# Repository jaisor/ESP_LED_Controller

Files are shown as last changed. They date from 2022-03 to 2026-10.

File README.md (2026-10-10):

# RingLight ESP LED Controller

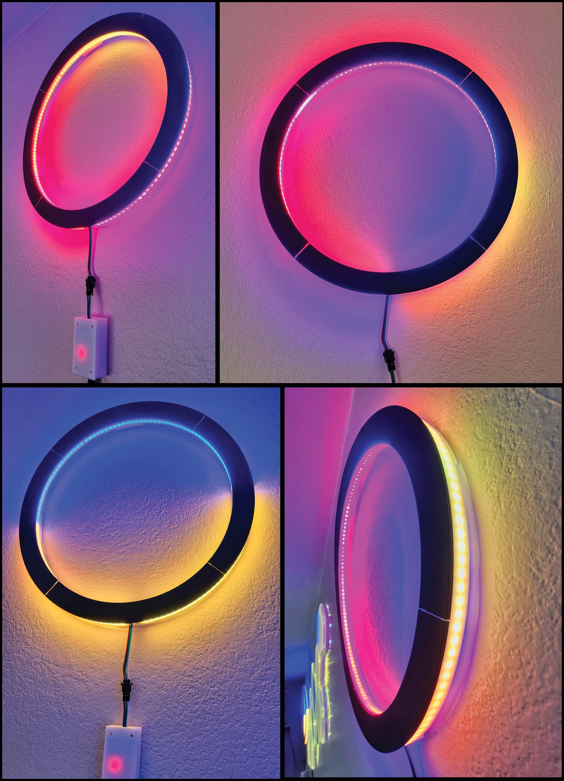
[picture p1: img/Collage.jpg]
Glamor shot


## Features
* Two LED rings - outer (141 LEDs) and inner (126 LEDs) wired up in series for a total of 267 LEDs
* Controlled by ESP32 (most stable). Code is compatible with ESP8266, but I was suffering stability issues with wifi and longer LED strips.
* WiFi connected and managed
    * creates a default AP, listening to http://192.168.4.1
    * capable of joining existing 2.4GHz networks
    * serves a webpage for managing LED - mode, brightness, cycling and power-save hours
    * LED setup page (`/led`) - layout (single strip, dual strip, ring light), LED count, data pin(s), chipset and color order
    * configuration export and import as a JSON file on the Device page
    * Mode Configurator (`/modes`) - define up to 8 custom modes: name, color palette (up to 8 colors, smooth or hard transitions), effect, direction, speed and palette repeats. Effects depend on the layout: color fade, edge to edge, twinkle, falling stars, flickering flame (from either end, both ends or the center - on a ring light in one or both rings), breathing, theater chase, scanner, color wipe and lightning everywhere, center to edge on strips, circling, ring halves and ring to ring on a ring light. A mode's **Code** button shows it as a short JSON code that can be pasted into another controller's configurator
* MQTT and Home Assistant (Device page) - set the broker and the controller shows up in Home Assistant through MQTT discovery as a light: on/off, brightness, and the modes of the current layout (custom modes included) as effects, plus WiFi signal and IP diagnostics. Other MQTT clients can use the same topics, see below
* Firmware update over WiFi - new `firmware.bin` file can be uploaded at `/update` after the IP address

## Components
* ESP32 - https://www.amazon.com/gp/product/B086MGH7JV
* JST SM 3PIN LED Connector - https://www.amazon.com/gp/product/B075K4HLTQ
* DC power connector - https://www.amazon.com/gp/product/B01N8VV78D
* WS2812B LED strip high density strips 144 LEDs per strip x 2 - https://www.amazon.com/gp/product/B088FKZWDQ
* DC 5v adapter - https://www.amazon.com/gp/product/B078RXZM4C

## 3D filament 
I used the ones below but likely many others will work. Make sure the white is translucent enough, print a 3 layer sheet and put it in-front of some LEDs.
* ESUN PLA+ warm white - https://www.amazon.com/gp/product/B01EKEMIIS
* ERYONE Matte PLA black - https://www.amazon.com/gp/product/B08HX1XF55

## Assembly and wiring

Print 4 of each:
* [Dark Ring](stl/DarkRing.stl)
* [Light Ring](stl/LightRing.stl)
* [Bridge Hanger](stl/Hanger.stl)

Assemble as described below. Rotate the light ring segments by 45 degrees so they join in the middle of the dark ring segments. 
This improves stability. If loose-fitting, use a few drops of superglue to set the dark and light rings together.
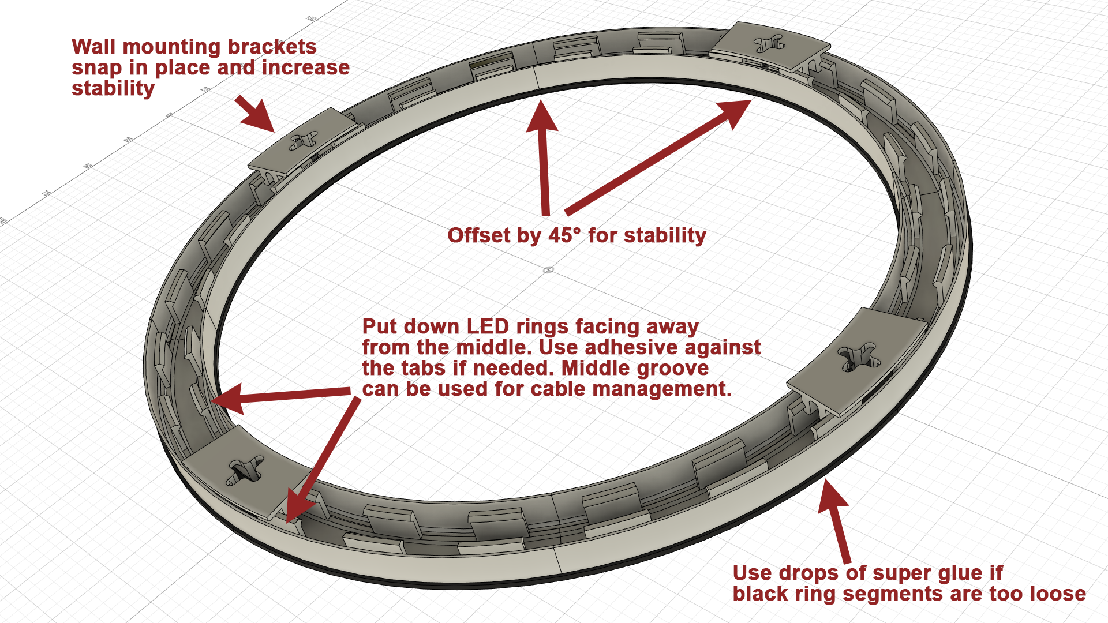
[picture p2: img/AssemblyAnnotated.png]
Assembly diagram


Cut the two LED strips to 141 and 126 LEDs. Keep as many of the existing wires and connectors as possible. 
Wire the strips data in series - outer first then inner. The beginning of the outer ring data pin goes to the connector data pin. 
Join the power wires in parallel: 5V/VCC together to the 5V connector pin; GND(-) together to GND on connector pin. 
Providing power to both start and ends of the strips reduces voltage sag and ensures even light at all brightness levels.

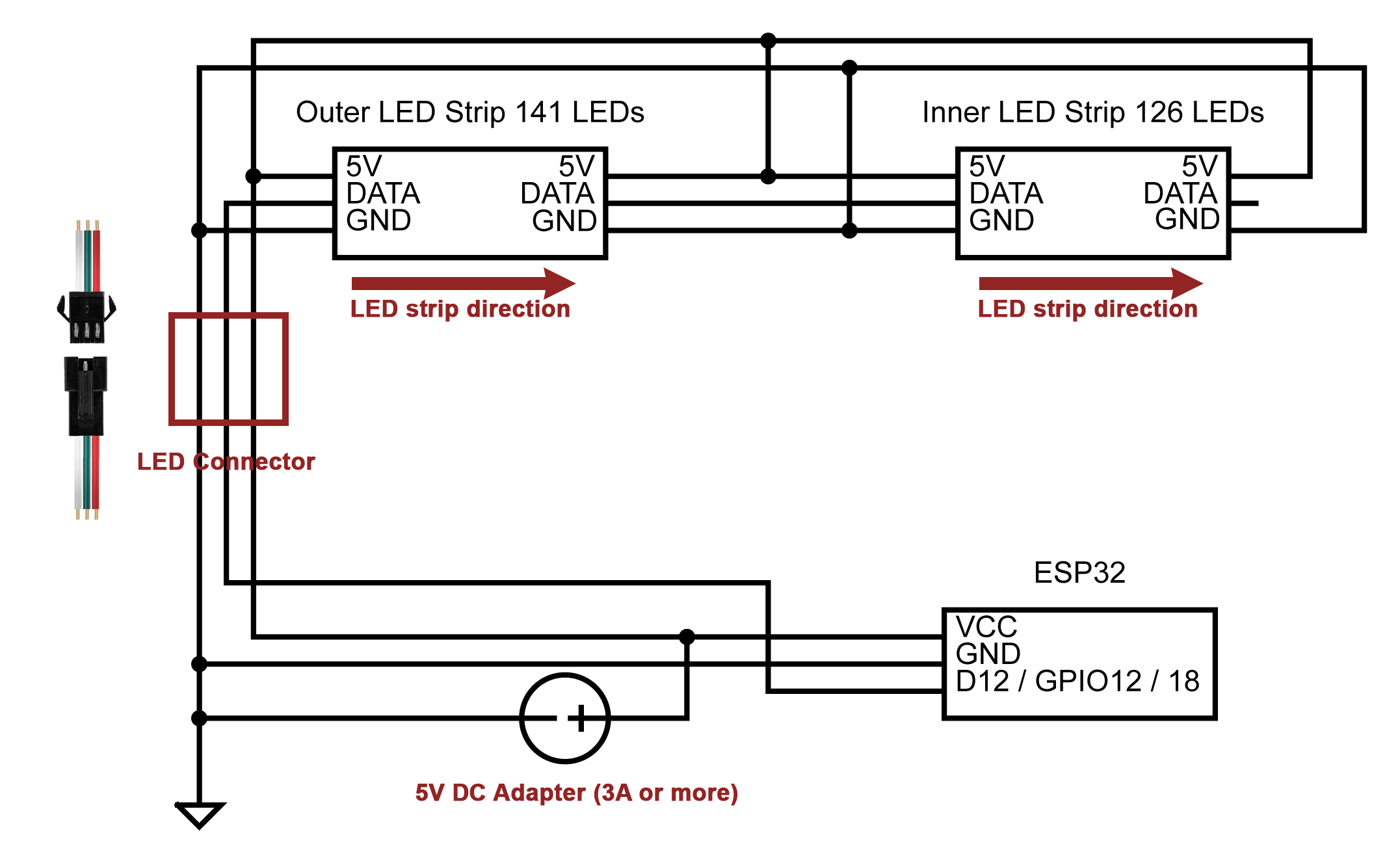
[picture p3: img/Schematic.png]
Schematic

Wiring Closeup
Wiring Complete

By default the LEDs data is connected to pin 12 on the ESP, but most other GPIO pins can be used if needed - pick the pin on the LED setup page.

__LED data pin = 12__ - GPIO12 - above VIN (5V), GND and GPIO13

After first boot, open `http://<device_ip>/led` (or ⚙️ → LED Setup) and set:
* Layout: __Ring light__
* Total LEDs: __267__, outer ring LEDs: __141__
* Chipset __WS2812B__, color order __GRB__

The ring modes (Slava Ukraini, Dual Ring, Ring ... Colors, Honey Amber, Ring Pride) only show up with the ring light layout.

ESP32 pins


Solder the power and data cables between the LED connector, ESP32 and DC connector as shown below, using the basic 3D printable enclosure.
The board is mounted above the DC connector with 3mm screws

ESP32 box assembled
ESP32 box

Enclosure STL files. Print in PLA, PETG or any other hard filament.
* [ESP32 Case STL](stl/ESP32Case.stl)
* [ESP32 Lid STL](stl/ESP32Lid.stl)

## Configuration.h

This file configures compile-time features and the defaults used after a factory reset, like:
* default LED data pin(s) and the list of GPIOs offered on the LED setup page
* WiFi AP name/password
* default LED layout, strip size, color order and brightness

Everything LED-hardware related can be changed at runtime on the LED setup page.
## MQTT

Enable it on the Device page by setting the MQTT server (and username/password if the broker requires one - the Home Assistant Mosquitto add-on does). Topics live under `<base topic>/<device id>`, both shown on the Device page:

| Topic | Direction | Payload |
| --- | --- | --- |
| `.../availability` | device → | `online` / `offline`, retained |
| `.../state` | device → | `{"state": "ON", "brightness": 0-255, "color_mode": "brightness", "effect": "<mode name>"}`, retained |
| `.../set` | → device | any of `{"state": "ON"/"OFF", "brightness": 0-255, "effect": "<mode name>"}` |
| `.../config` | → device | configuration JSON, same fields as the Device page backup file; saved, and the device reboots for WiFi, MQTT or LED hardware changes |
| `.../json` | device → | telemetry (IP, RSSI, uptime, mode, ...), every 5 minutes, retained |

With Home Assistant discovery enabled the device publishes its entities to `homeassistant/light/<device id>/config` and `homeassistant/sensor/<device id>_*/config`, and re-publishes them when Home Assistant restarts or the mode list changes.

## Migrating to the larger app partitions

Firmware for the `esp32`, `esp32c3` and `esp32s3` environments is built for `min_spiffs.csv` (two 1.9MB app slots); it no longer fits the 1.25MB slots of the framework's `default.csv` that older builds used. A normal OTA update can't fix that - it never rewrites the partition table - so `/update` on an older device rejects the new `firmware.bin` (safely, nothing changes). Flash over USB where you can; for devices that are hard to reach there is a one-off migrator firmware:

1. Build it for the board: `pio run -e esp32_migrator` (or `esp32c3_migrator`, `esp32s3_migrator`). The Xiao ESP32-S3 doesn't need it - its 8MB layout didn't change.
2. Upload `.pio/build/<env>_migrator/firmware.bin` through the device's existing `/update` page.
3. The migrator joins the saved WiFi network (or opens an access point `<name>_<chip id>_migrator`, password `password123`, at http://192.168.4.1) and shows the current partition table. Settings are only read, never changed.
4. Click **Migrate partition table**. It writes `min_spiffs.csv` to the partition table, verifies it and reboots into itself.
5. Upload the normal `firmware.bin` on the migrator's page. The controller comes back with its settings.

The migrator only writes the table when it recognizes `default.csv`, refuses on flash encryption or secure boot, and puts the old table back if the write doesn't verify. The write itself takes a fraction of a second, but a power cut during it leaves a board that needs USB - so try it on a board within USB reach first.

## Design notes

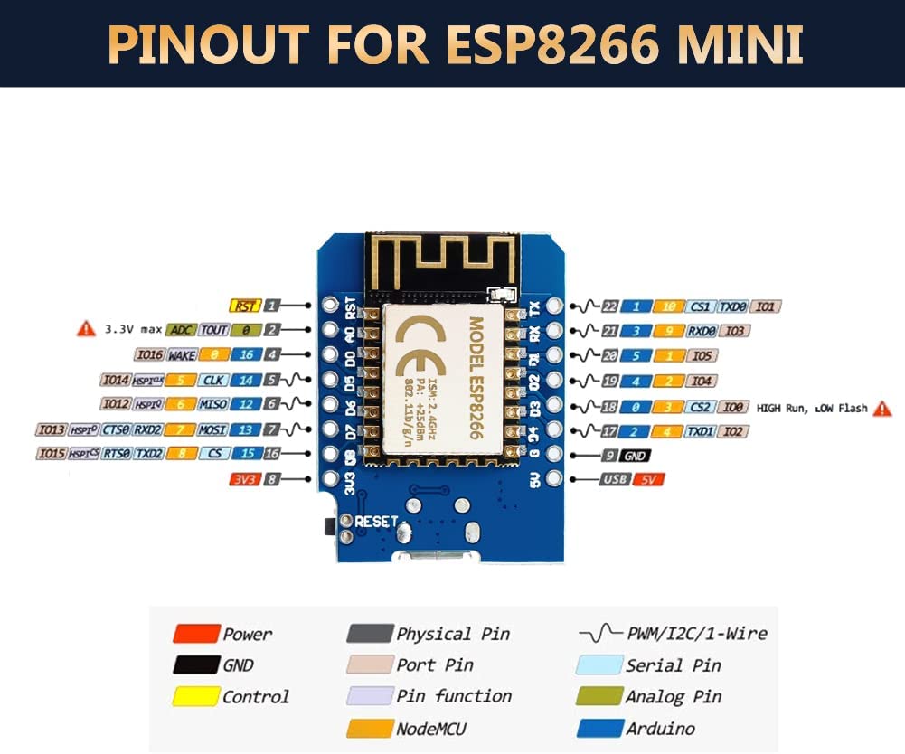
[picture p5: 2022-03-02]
img/ESP8266_pins.jpg

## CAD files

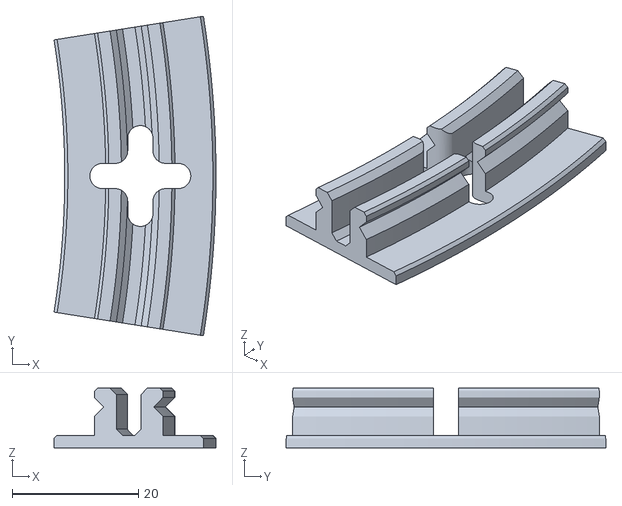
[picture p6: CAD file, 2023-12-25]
stl/Hanger.stl
25.7 x 50.7 x 9.50

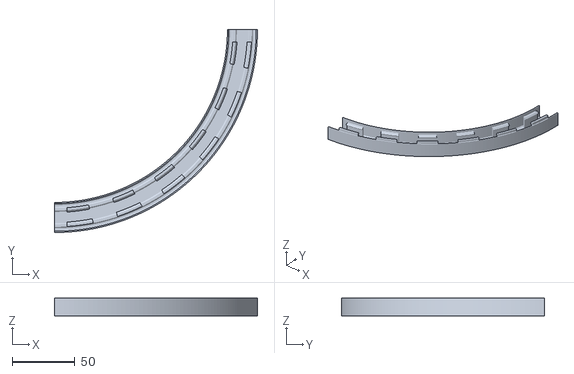
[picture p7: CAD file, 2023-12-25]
stl/LightRing.stl
162.0 x 162.0 x 14.0

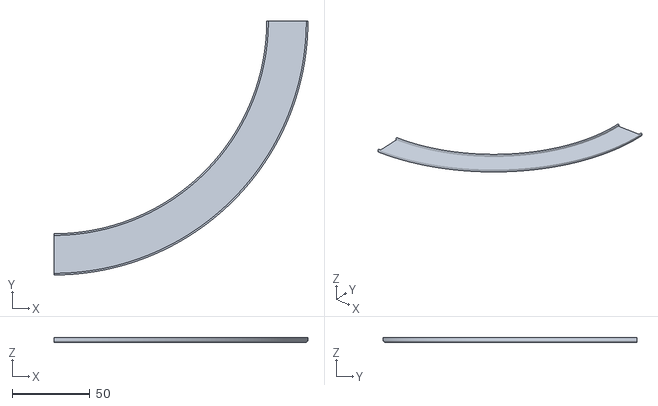
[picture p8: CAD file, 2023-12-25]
stl/DarkRing.stl
163.3 x 163.3 x 3.00

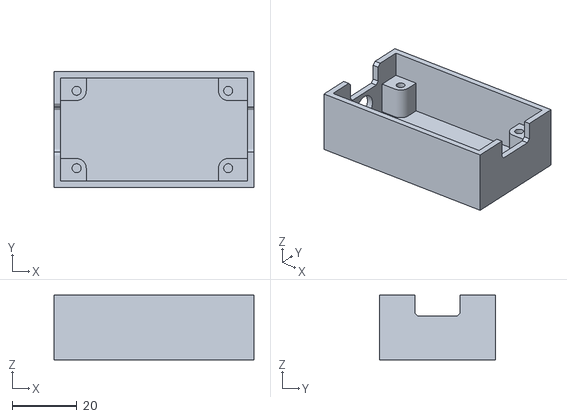
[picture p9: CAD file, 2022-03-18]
stl/ESP32Case.stl
62.0 x 36.0 x 20.0

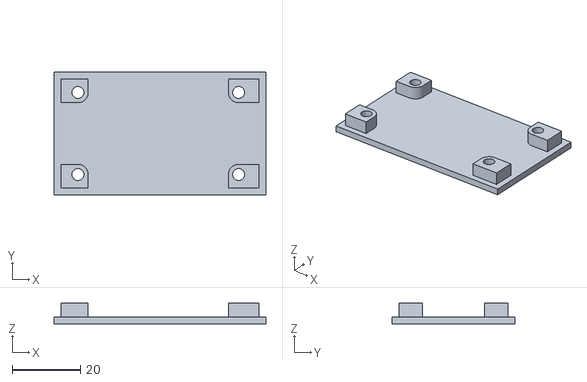
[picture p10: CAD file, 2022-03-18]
stl/ESP32Lid.stl
62.0 x 36.0 x 6.00

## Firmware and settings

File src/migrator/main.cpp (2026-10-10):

// Partition migrator - a one-off firmware, built by the *_migrator environments.
//
// Moves an ESP32 / ESP32-C3 / ESP32-S3 with 4MB flash from the framework's default.csv (two 1.25MB
// app slots) to min_spiffs.csv (two 1.9MB slots) over the air, since a normal OTA update never
// rewrites the partition table and the current firmware no longer fits a 1.25MB slot.
//
//   1. Upload this firmware with the old firmware's /update page. It lands in app0 or app1.
//   2. If it booted from app1 it copies itself to app0 and reboots: app0 starts at 0x10000 in both
//      tables, so it keeps running from there after the switch. Only app1 and what follows move.
//   3. "Migrate" on its web page writes the new table to 0x8000 and reboots.
//   4. Its web page then takes the real firmware.bin, which goes into the new 1.9MB app1.
//
// nvs (the saved configuration) and otadata sit at the same offsets in both tables and are left
// alone. The table is only written when the current one is recognized as default.csv, and the
// write is read back and the old table put back if it doesn't match. A power cut during the
// fraction of a second the write takes still leaves a board that needs USB.

#include <Arduino.h>
#include <WiFi.h>
#include <WebServer.h>
#include <Update.h>
#include <MD5Builder.h>
#include <nvs.h>
#include <esp_flash.h>
#include <esp_flash_internal.h>
#include <esp_flash_partitions.h>
#include <esp_flash_encrypt.h>
#include <esp_secure_boot.h>
#include <esp_image_format.h>
#include <esp_ota_ops.h>
#include <esp_partition.h>

#include "Configuration.h"
#include "min_spiffs_table.h"

#define MIN_SPIFFS_TABLE_MD5_OFFSET 192  // MD5 entry follows the 6 partition entries
#define WIFI_CONNECT_TIMEOUT_MS 20000

enum table_layout_t { TABLE_UNKNOWN, TABLE_DEFAULT, TABLE_MIN_SPIFFS };

static WebServer server(WEB_SERVER_PORT);
alignas(4) static uint8_t tableSector[ESP_PARTITION_TABLE_SIZE];  // Partition table as read at boot
static table_layout_t layout = TABLE_UNKNOWN;
static String tableProblem;     // Why the layout isn't recognized
static String blockers;         // Why the table can't be migrated, one <li> per reason
static String lastError;
static bool uploadAccepted = false;

static const char *LAYOUT_NAMES[] = {"not recognized", "default.csv (1.25MB app slots)", "min_spiffs.csv (1.9MB app slots)"};

// ---------------------------------------------------------------------------- partition table

static bool entryMatches(const esp_partition_info_t &e, uint8_t type, uint8_t subtype, uint32_t offset, uint32_t size) {
  return e.type == type && e.subtype == subtype && e.pos.offset == offset && e.pos.size == size;
}

static table_layout_t classifyTable(const uint8_t *table, String &problem) {
  if (!memcmp(table, MIN_SPIFFS_TABLE, sizeof(MIN_SPIFFS_TABLE))) {
    return TABLE_MIN_SPIFFS;
  }

  // default.csv: nvs, otadata, app0, app1 exactly as below. What follows app1 (spiffs, coredump) is
  // data that min_spiffs reuses, and older framework versions laid it out differently, so it only
  // has to stay above the end of app1.
  const esp_partition_info_t *entries = (const esp_partition_info_t*)table;
  bool nvs = false, otadata = false, app0 = false, app1 = false;
  for (size_t i = 0; i < ESP_PARTITION_TABLE_MAX_ENTRIES && entries[i].magic == ESP_PARTITION_MAGIC; i++) {
    const esp_partition_info_t &e = entries[i];
    char labelBuffer[sizeof(e.label) + 1] = {};  // Labels aren't terminated when they use all 16 bytes
    memcpy(labelBuffer, e.label, sizeof(e.label));
    String label = labelBuffer;
    if (label == "nvs" && entryMatches(e, PART_TYPE_DATA, 0x02, 0x9000, 0x5000)) nvs = true;
    else if (label == "otadata" && entryMatches(e, PART_TYPE_DATA, PART_SUBTYPE_DATA_OTA, 0xE000, 0x2000)) otadata = true;
    else if (label == "app0" && entryMatches(e, PART_TYPE_APP, 0x10, 0x10000, 0x140000)) app0 = true;
    else if (label == "app1" && entryMatches(e, PART_TYPE_APP, 0x11, 0x150000, 0x140000)) app1 = true;
    else if (e.type == PART_TYPE_APP || e.pos.offset < 0x290000) {
      problem = String("unexpected partition '") + label + "'";
      return TABLE_UNKNOWN;
    }
  }
  if (!(nvs && otadata && app0 && app1)) {
    problem = "nvs, otadata, app0 or app1 differ from default.csv";
    return TABLE_UNKNOWN;
  }
  return TABLE_DEFAULT;
}

static String describeTable(const uint8_t *table) {
  String s;
  const esp_partition_info_t *entries = (const esp_partition_info_t*)table;
  for (size_t i = 0; i < ESP_PARTITION_TABLE_MAX_ENTRIES && entries[i].magic == ESP_PARTITION_MAGIC; i++) {
    char line[96];
    snprintf(line, sizeof(line), "%-9.16s type %u/0x%02x  0x%06x  %4u KB\n", (const char*)entries[i].label,
      entries[i].type, entries[i].subtype, (unsigned)entries[i].pos.offset, (unsigned)(entries[i].pos.size / 1024));
    s += line;
  }
  return s;
}

static bool embeddedTableValid() {
  MD5Builder md5;
  md5.begin();
  md5.add(MIN_SPIFFS_TABLE, MIN_SPIFFS_TABLE_MD5_OFFSET);
  md5.calculate();
  uint8_t digest[16];
  md5.getBytes(digest);
  const uint8_t *entry = MIN_SPIFFS_TABLE + MIN_SPIFFS_TABLE_MD5_OFFSET;
  return entry[0] == 0xEB && entry[1] == 0xEB && !memcmp(digest, entry + ESP_PARTITION_MD5_OFFSET, sizeof(digest));
}

// Erase and write the partition table sector, read it back. The IDF refuses writes below the first
// partition unless its OS-level protection is lifted for the duration.
static esp_err_t writeTableSector(const uint8_t *sector) {
  alignas(4) static uint8_t verify[ESP_PARTITION_TABLE_SIZE];
  esp_err_t err = esp_flash_erase_region(NULL, ESP_PARTITION_TABLE_OFFSET, ESP_PARTITION_TABLE_SIZE);
  if (err == ESP_OK) err = esp_flash_write(NULL, sector, ESP_PARTITION_TABLE_OFFSET, ESP_PARTITION_TABLE_SIZE);
  if (err == ESP_OK) err = esp_flash_read(NULL, verify, ESP_PARTITION_TABLE_OFFSET, ESP_PARTITION_TABLE_SIZE);
  if (err == ESP_OK && memcmp(verify, sector, ESP_PARTITION_TABLE_SIZE)) err = ESP_ERR_INVALID_CRC;
  return err;
}

static bool migrateTable(String &error) {
  alignas(4) static uint8_t sector[ESP_PARTITION_TABLE_SIZE];
  memset(sector, 0xFF, sizeof(sector));
  memcpy(sector, MIN_SPIFFS_TABLE, sizeof(MIN_SPIFFS_TABLE));

  Serial.println("Writing min_spiffs partition table");
  esp_flash_app_disable_protect(true);
  esp_err_t err = ESP_FAIL;
  for (int attempt = 0; attempt < 3 && err != ESP_OK; attempt++) {
    err = writeTableSector(sector);
    Serial.printf("  attempt %d: %s\n", attempt + 1, esp_err_to_name(err));
    if (err == ESP_ERR_NOT_ALLOWED || err == ESP_ERR_NOT_SUPPORTED) break;  // Refused before erasing anything
  }
  bool restored = false;
  if (err != ESP_OK && err != ESP_ERR_NOT_ALLOWED && err != ESP_ERR_NOT_SUPPORTED) {
    // Put the table the device booted with back, so it still boots the way it did
    for (int attempt = 0; attempt < 3 && !restored; attempt++) {
      restored = writeTableSector(tableSector) == ESP_OK;
    }
  }
  esp_flash_app_disable_protect(false);

  if (err == ESP_OK) {
    return true;
  }
  error = String("writing the partition table failed: ") + esp_err_to_name(err);
  if (err == ESP_ERR_NOT_ALLOWED || err == ESP_ERR_NOT_SUPPORTED) {
    error += ". Nothing was changed.";
  } else if (restored) {
    error += ". The previous table was put back; the device still boots as before.";
  } else {
    error += ". RESTORING THE PREVIOUS TABLE FAILED TOO - do not reboot, the device will need USB to recover.";
  }
  return false;
}

// ---------------------------------------------------------------------------- app slot

// app1 moves in the new table, so the migrator has to run from app0 before rewriting it
static bool copySelfToApp0(String &error) {
  const esp_partition_t *running = esp_ota_get_running_partition();
  const esp_partition_t *app0 = esp_partition_find_first(ESP_PARTITION_TYPE_APP, ESP_PARTITION_SUBTYPE_APP_OTA_0, NULL);
  if (!app0) {
    error = "no app0 partition";
    return false;
  }

  esp_partition_pos_t pos = { running->address, running->size };
  esp_image_metadata_t image;
  if (esp_image_get_metadata(&pos, &image) != ESP_OK) {
    error = "can't read the running image";
    return false;
  }

  Serial.printf("Copying %u byte image from %s to app0\n", (unsigned)image.image_len, running->label);
  esp_ota_handle_t handle;
  esp_err_t err = esp_ota_begin(app0, image.image_len, &handle);
  static uint8_t buffer[4096];
  for (size_t offset = 0; err == ESP_OK && offset < image.image_len; offset += sizeof(buffer)) {
    size_t length = min(sizeof(buffer), (size_t)(image.image_len - offset));
    err = esp_partition_read(running, offset, buffer, length);
    if (err == ESP_OK) err = esp_ota_write(handle, buffer, length);
  }
  if (err == ESP_OK) err = esp_ota_end(handle);
  if (err == ESP_OK) err = esp_ota_set_boot_partition(app0);
  if (err != ESP_OK) {
    error = String("copying to app0 failed: ") + esp_err_to_name(err);
    return false;
  }
  return true;
}

// ---------------------------------------------------------------------------- WiFi

// Reads the main firmware's saved WiFi network without writing anything: the EEPROM library lives in
// the NVS blob "eeprom", configuration_t starts at EEPROM_CONFIGURATION_START
static bool readSavedWifi(String &ssid, String &password) {
  nvs_handle_t handle;
  if (nvs_open("eeprom", NVS_READONLY, &handle) != ESP_OK) {
    return false;
  }
  size_t length = 0;
  bool ok = false;
  if (nvs_get_blob(handle, "eeprom", NULL, &length) == ESP_OK
      && length >= EEPROM_CONFIGURATION_START + offsetof(configuration_t, _loaded) + sizeof(configuration_t::_loaded)) {
    uint8_t *blob = (uint8_t*)malloc(length);
    if (blob && nvs_get_blob(handle, "eeprom", blob, &length) == ESP_OK) {
      const uint8_t *config = blob + EEPROM_CONFIGURATION_START;
      char loaded[sizeof(configuration_t::_loaded) + 1] = {};
      memcpy(loaded, config + offsetof(configuration_t, _loaded), sizeof(configuration_t::_loaded));
      if (!strcmp(loaded, "jaisor")) {
        char value[sizeof(configuration_t::wifiPassword) + 1] = {};
        memcpy(value, config + offsetof(configuration_t, wifiSsid), sizeof(configuration_t::wifiSsid));
        ssid = value;
        memset(value, 0, sizeof(value));
        memcpy(value, config + offsetof(configuration_t, wifiPassword), sizeof(configuration_t::wifiPassword));
        password = value;
        ok = ssid.length() > 0;
      }
    }
    free(blob);
  }
  nvs_close(handle);
  return ok;
}

static void startWifi() {
  String ssid, password;
  if (readSavedWifi(ssid, password)) {
    Serial.printf("Connecting to '%s'\n", ssid.c_str());
    WiFi.mode(WIFI_STA);
    WiFi.begin(ssid.c_str(), password.c_str());
    unsigned long start = millis();
    while (WiFi.status() != WL_CONNECTED && millis() - start < WIFI_CONNECT_TIMEOUT_MS) {
      delay(250);
    }
    if (WiFi.status() == WL_CONNECTED) {
      Serial.printf("Connected, open http://%s/\n", WiFi.localIP().toString().c_str());
      return;
    }
    Serial.println("Connecting failed");
  }
  uint32_t chipId = 0;
  for (int i = 0; i < 17; i += 8) {
    chipId |= ((ESP.getEfuseMac() >> (40 - i)) & 0xff) << i;
  }
  String apName = String(DEVICE_NAME) + "_" + chipId + "_migrator";
  WiFi.mode(WIFI_AP);
  WiFi.softAP(apName.c_str(), WIFI_FALLBACK_PASS);
  Serial.printf("Access point '%s' / '%s', open http://%s/\n", apName.c_str(), WIFI_FALLBACK_PASS, WiFi.softAPIP().toString().c_str());
}

// ---------------------------------------------------------------------------- web

static String pageTop() {
  return F("<!doctype html><html><head><meta charset='utf-8'><meta name='viewport' content='width=device-width, initial-scale=1'>"
    "<title>Partition migrator</title><style>body{font-family:sans-serif;max-width:46rem;margin:1rem auto;padding:0 1rem;line-height:1.4}"
    "pre{background:#eee;padding:.5rem;overflow-x:auto}.err{color:#b00}button{font-size:1rem;padding:.5rem 1rem}</style></head><body>"
    "<h2>ESP LED Controller - partition migrator</h2>");
}

static void handleStatus() {
  const esp_partition_t *running = esp_ota_get_running_partition();
  uint32_t flashSize = 0;
  esp_flash_get_size(NULL, &flashSize);

  String page = pageTop();
  page += "<p>Chip <b>" + String(ESP.getChipModel()) + "</b>, " + (flashSize / (1024 * 1024)) + " MB flash, running from <b>"
    + running->label + "</b> at 0x" + String(running->address, HEX) + "</p>";
  page += String("<p>Partition table: <b>") + LAYOUT_NAMES[layout] + "</b>"
    + (tableProblem.length() ? " - " + tableProblem : "") + "</p><pre>" + describeTable(tableSector) + "</pre>";
  if (lastError.length()) {
    page += "<p class='err'>" + lastError + "</p>";
  }

  if (layout == TABLE_MIN_SPIFFS) {
    page += F("<h3>Step 2 of 2: upload the firmware</h3>"
      "<p>The partition table is migrated. Upload the ESP LED Controller <code>firmware.bin</code> built for this board "
      "(<code>.pio/build/&lt;env&gt;/firmware.bin</code>). It replaces this migrator and keeps the saved settings.</p>"
      "<form method='POST' action='update' enctype='multipart/form-data'>"
      "<input type='file' name='firmware' accept='.bin' required> <button type='submit'>Upload and reboot</button></form>");
  } else if (layout == TABLE_DEFAULT && !blockers.length()) {
    page += F("<h3>Step 1 of 2: migrate the partition table</h3>"
      "<p>Writes <code>min_spiffs.csv</code> to the partition table and reboots into this migrator. Settings are kept. "
      "The write takes a fraction of a second; a power cut during it leaves a board that needs USB to recover.</p>"
      "<form method='POST' action='migrate' onsubmit=\"return confirm('Rewrite the partition table now?')\">"
      "<button type='submit'>Migrate partition table</button></form>");
  } else {
    page += "<h3>Not migrating</h3><ul>" + blockers + "</ul><p>The partition table was not touched. Flash this board over USB instead.</p>";
  }
  page += F("</body></html>");
  server.send(200, "text/html; charset=utf-8", page);
}

static void handleMigrate() {
  if (layout != TABLE_DEFAULT || blockers.length()) {
    server.sendHeader("Location", "/");
    server.send(303);
    return;
  }
  String error;
  if (!migrateTable(error)) {
    lastError = error;
    server.sendHeader("Location", "/");
    server.send(303);
    return;
  }
  server.send(200, "text/html; charset=utf-8", pageTop() +
    F("<p>Partition table migrated. Rebooting - reload this page in about 30 seconds to upload the firmware.</p></body></html>"));
  delay(500);
  ESP.restart();
}

static void handleUploadDone() {
  if (uploadAccepted && !Update.hasError()) {
    server.send(200, "text/html; charset=utf-8", pageTop() +
      F("<p>Firmware uploaded. Rebooting into it - the controller's own page is back in about 30 seconds.</p></body></html>"));
    delay(500);
    ESP.restart();
  } else {
    lastError = uploadAccepted ? String("upload failed: ") + Update.errorString() : String("upload refused: partition table not migrated");
    server.sendHeader("Location", "/");
    server.send(303);
  }
}

static void handleUploadData() {
  HTTPUpload &upload = server.upload();
  switch (upload.status) {
    case UPLOAD_FILE_START:
      uploadAccepted = layout == TABLE_MIN_SPIFFS;
      if (uploadAccepted) {
        Serial.printf("Receiving %s\n", upload.filename.c_str());
        Update.begin(UPDATE_SIZE_UNKNOWN);
      }
      break;
    case UPLOAD_FILE_WRITE:
      if (uploadAccepted) Update.write(upload.buf, upload.currentSize);
      break;
    case UPLOAD_FILE_END:
      if (uploadAccepted) Update.end(true);
      Serial.printf("Upload done, %u bytes, %s\n", (unsigned)upload.totalSize, Update.hasError() ? Update.errorString() : "ok");
      break;
    case UPLOAD_FILE_ABORTED:
      if (uploadAccepted) Update.abort();
      break;
    default:
      break;
  }
}

// ---------------------------------------------------------------------------- setup / loop

static void addBlocker(const String &reason) {
  blockers += "<li>" + reason + "</li>";
  Serial.printf("Blocked: %s\n", reason.c_str());
}

void setup() {
  Serial.begin(SERIAL_MONITOR_BAUD);
  delay(500);
  Serial.println("\nPartition migrator");

  if (esp_flash_read(NULL, tableSector, ESP_PARTITION_TABLE_OFFSET, sizeof(tableSector)) != ESP_OK) {
    tableProblem = "can't read it";
  } else {
    layout = classifyTable(tableSector, tableProblem);
  }
  Serial.printf("Partition table: %s %s\n%s", LAYOUT_NAMES[layout], tableProblem.c_str(), describeTable(tableSector).c_str());

  const esp_partition_t *running = esp_ota_get_running_partition();
  uint32_t flashSize = 0;
  esp_flash_get_size(NULL, &flashSize);

  if (layout == TABLE_UNKNOWN) addBlocker("the partition table isn't the framework's default.csv");
  if (layout == TABLE_DEFAULT) {
    if (flashSize < 0x400000) addBlocker("min_spiffs.csv needs 4MB of flash");
    if (esp_flash_encryption_enabled()) addBlocker("flash encryption is enabled");
    if (esp_secure_boot_enabled()) addBlocker("secure boot is enabled");
    if (!embeddedTableValid()) addBlocker("the embedded partition table fails its MD5 check");

    if (!blockers.length() && running->address != 0x10000) {
      String error;
      if (copySelfToApp0(error)) {
        Serial.println("Rebooting into app0");
        delay(200);
        ESP.restart();
      }
      addBlocker(error);
    }
  }

  startWifi();
  server.on("/", HTTP_GET, handleStatus);
  server.on("/migrate", HTTP_POST, handleMigrate);
  server.on("/update", HTTP_POST, handleUploadDone, handleUploadData);
  server.onNotFound([]() { server.sendHeader("Location", "/"); server.send(303); });
  server.begin();
}

void loop() {
  server.handleClient();
  delay(2);
}

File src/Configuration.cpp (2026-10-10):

#include <Arduino.h>
#include <EEPROM.h>
#include <version.h>
#include "Configuration.h"
#ifdef LED
  #include <FastLED.h>
  #include "modes/CustomMode.h"
#endif

configuration_t configuration;
// ESP8266 emulates EEPROM in a single 4KB flash sector
static_assert(EEPROM_CONFIGURATION_START + sizeof(configuration_t) <= 4096, "configuration_t no longer fits in EEPROM");
#ifdef WEB_LOGGING
  StringPrint logStream;

  void trimLogStream() {
    if (logStream.str().length() > WEB_LOG_MAX_SIZE) {
      // Keep only the most recent half of the buffer
      String s = logStream.str().c_str();
      logStream.str("");
      logStream.print(s.substring(s.length() - WEB_LOG_MAX_SIZE / 2));
    }
  }
#endif

uint8_t EEPROM_initAndCheckFactoryReset() {
  Log.noticeln("Configuration size: %i", sizeof(configuration_t));
  
  EEPROM.begin(sizeof(configuration_t) + EEPROM_FACTORY_RESET + 1);
  uint8_t resetCounter = EEPROM.read(EEPROM_FACTORY_RESET);

  Log.noticeln("Factory reset counter: %i", resetCounter);
  Log.noticeln("EEPROM length: %i", EEPROM.length());

  // Bump reset counter
  EEPROM.write(EEPROM_FACTORY_RESET, resetCounter + 1);
  EEPROM.commit();

  return resetCounter;
}

void EEPROM_clearFactoryReset() {
  #if defined(ESP32)
  //portMUX_TYPE mx = portMUX_INITIALIZER_UNLOCKED;
  //taskENTER_CRITICAL(&mx);
  #endif
  
  EEPROM.write(EEPROM_FACTORY_RESET, 0);
  EEPROM.commit();

  #if defined(ESP32)
  //taskEXIT_CRITICAL(&mx);
  #endif
}

void EEPROM_saveConfig() {
  Log.info("Saving configuration to EEPROM ... ");

  #if defined(ESP32)
  //portMUX_TYPE mx = portMUX_INITIALIZER_UNLOCKED;
  //taskENTER_CRITICAL(&mx);
  #endif
  
  EEPROM.put(EEPROM_CONFIGURATION_START, configuration);
  EEPROM.commit();

  #if defined(ESP32)
  //taskEXIT_CRITICAL(&mx);
  #endif
  
  Log.verboseln("Saved");
}

void EEPROM_loadConfig() {

  configuration = {};
  EEPROM.get(EEPROM_CONFIGURATION_START, configuration);

  Log.noticeln("Configuration loaded: %s", configuration._loaded);

  if (strcmp(configuration._loaded, "jaisor")) {
    // blank
    Log.infoln("Blank configuration, loading defaults");
    strcpy(configuration._loaded, "jaisor");
    strcpy(configuration.name, DEVICE_NAME);
    #ifdef LED
      configuration.ledMode = 0;
      configuration.ledType = 0; // Default to WS281B
      configuration.ledCycleModeMs = LED_CHANGE_MODE_SEC * 1000;
      configuration.ledDelayMs = 10;
      configuration.ledBrightness = LED_BRIGHTNESS;
      configuration.ledStripSize = LED_STRIP_SIZE;
      configuration.psLedBrightness = 1.0f;
      configuration.psStartHour = 0;
      configuration.psEndHour = 0;
      configuration.cycleModesCount = 0;  // 0 means cycle through all modes
      for (int i = 0; i < 32; i++) {
        configuration.cycleModesList[i] = 0;
      }
    #endif
    #ifdef WIFI
      strcpy(configuration.ntpServer, NTP_SERVER);
      configuration.gmtOffset_sec = NTP_GMT_OFFSET_SEC;
      configuration.daylightOffset_sec = NTP_DAYLIGHT_OFFSET_SEC;
      #if defined(CONFIG_IDF_TARGET_ESP32C3) || defined(CONFIG_IDF_TARGET_ESP32S3)
        configuration.wifiPower = 34; // ESP32-C3 default: WIFI_POWER_8_5dBm (8.5dBm)
      #else
        configuration.wifiPower = 82;
      #endif
    #endif
    configuration.ledEnabled = false;
    #ifdef LED
      configuration._ledLoaded[0] = '\0';
      configuration._customModesLoaded[0] = '\0';
    #endif
    configuration._mqttLoaded[0] = '\0';
  }

#ifdef LED
  if (strcmp(configuration._ledLoaded, "led")) {
    // Blank, or saved by firmware that had the LED hardware compiled in - use those same defaults
    Log.infoln("No LED hardware configuration, loading defaults");
    strcpy(configuration._ledLoaded, "led");
    configuration.ledLayout = LED_LAYOUT;
    configuration.ledPin = LED_PIN;
    configuration.ledPin2 = LED_PIN_2;
    configuration.ledColorOrder = static_cast<uint8_t>(LED_COLOR_ORDER);
    configuration.ledStripSize2 = LED_STRIP_SIZE_2;
    configuration.ledRingOuterSize = LED_RING_OUTER_SIZE;
    configuration.ledMirror = false;
  }
  if (strcmp(configuration._customModesLoaded, "cm1")) {
    Log.infoln("No custom modes, clearing slots");
    strcpy(configuration._customModesLoaded, "cm1");
    memset(configuration.customModes, 0, sizeof(configuration.customModes));
  }
#endif

  if (strcmp(configuration._mqttLoaded, "mq1")) {
    Log.infoln("No MQTT configuration, loading defaults");
    strcpy(configuration._mqttLoaded, "mq1");
    #ifdef LED
      configuration.ledPower = true;
    #endif
    #ifdef WIFI
      strcpy(configuration.mqttServer, "");
      configuration.mqttPort = MQTT_PORT;
      strcpy(configuration.mqttUser, "");
      strcpy(configuration.mqttPassword, "");
      strcpy(configuration.mqttTopic, MQTT_TOPIC);
      configuration.mqttDiscovery = true;
    #endif
  }
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

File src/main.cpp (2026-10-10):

#include <Arduino.h>
#include <ArduinoLog.h>


#if !( defined(ESP32) ) && !( defined(ESP8266) )
  #error This code is intended to run on ESP8266 platform! Please check your Tools->Board setting.
#endif

#include "wifi/WifiManager.h"
#include "Device.h"
#include "LedManager.h"

CWifiManager *wifiManager;
CDevice *device;
CLEDManager *ledManager;

unsigned long tsSmoothBoot;
bool smoothBoot;

void setup() {
  randomSeed(analogRead(0));
  
  #ifdef ESP8266
    pinMode(D0, WAKEUP_PULLUP);
  #endif
  pinMode(INTERNAL_LED_PIN, OUTPUT);

  #ifndef DISABLE_LOGGING
  Serial.begin(SERIAL_MONITOR_BAUD);
  // Bounded wait. On the USB-CDC targets (ESP32-C3/S3) Serial only becomes true once a
  // terminal attaches, so an unbounded `while (!Serial)` stops setup() from ever reaching
  // loop() - and loop() is where the factory reset counter is cleared, so three headless
  // boots in that state wipe the stored configuration.
  unsigned long tsSerial = millis();
  while (!Serial && millis() - tsSerial < 3000) { delay(10); }
  delay(100);
  Log.begin(LOG_LEVEL, &Serial);
  Log.infoln(F("\n\nInitializing..."));
    #ifdef WEB_LOGGING
    Log.addHandler(&logStream);
    Log.infoln(F("Initializing web log..."));
    #endif
  #elif defined(WEB_LOGGING)
    Log.begin(WEB_LOG_LEVEL, &logStream);
    Log.infoln(F("Initializing web log..."));
  #endif

  if (EEPROM_initAndCheckFactoryReset() >= 3) {
    Log.warningln("Factory reset conditions met!");
    EEPROM_wipe();  
  }

  tsSmoothBoot = millis();
  smoothBoot = false;

  EEPROM_loadConfig();

  Log.infoln("Configuration loaded");
  intLEDOn();

  device = new CDevice();
  wifiManager = new CWifiManager();
  wifiManager->setDevice(device);

  ledManager = new CLEDManager();
  ledManager->setModeChangeCallback([]() {
    if (wifiManager) {
      wifiManager->updateModeChangeTime();
    }
  });
  ledManager->setChargingStartCallback([]() {
    #ifdef OLED
    if (device) {
      device->displayTemporaryMessage("Charging...", 5000);
    }
    #endif
  });
  ledManager->setup();

  wifiManager->setModes(ledManager->getModes(), ledManager->getLayout());
  wifiManager->updateModeChangeTime();

  Log.noticeln("Setup completed!");
}

void loop() {
  static unsigned long tsMillis = millis();

  if (!smoothBoot && millis() - tsSmoothBoot > FACTORY_RESET_CLEAR_TIMER_MS) {
    smoothBoot = true;
    EEPROM_clearFactoryReset();
    Log.noticeln("Device booted smoothly!");
    Log.verboseln("LED brightness: '%i'", 255 * CONFIG_getLedBrightness());
  }
  
  device->loop();
  wifiManager->loop();
  ledManager->loop();

  #ifdef WEB_LOGGING
  trimLogStream();
  #endif

  if (wifiManager->isRebootNeeded()) {
    return;
  }

  delay(5);
  yield();
}

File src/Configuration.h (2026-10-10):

#pragma once

#include <Arduino.h>
#include <functional>
#include <ArduinoLog.h>
#include <StreamUtils.h>

#define WIFI        // 2.4Ghz wifi access point
#define LED         // Individually addressible LED strip
//#define OLED        // OLED display
//#define BUTTONS     // Buttons

//#define KEYPAD      // Buttons

//#define DEBUG_MOCK_HP
//#define DISABLE_LOGGING
#ifndef DISABLE_LOGGING
  #define LOG_LEVEL LOG_LEVEL_VERBOSE
#endif

#define WEB_LOGGING // When enabled log is available at http://<device_ip>/log
#ifdef WEB_LOGGING
  #define WEB_LOG_LEVEL LOG_LEVEL_VERBOSE
  #define WEB_LOG_MAX_SIZE 8192  // Cap log buffer to 8KB to prevent heap exhaustion
#endif

#if defined(CONFIG_IDF_TARGET_ESP32C3) || defined(CONFIG_IDF_TARGET_ESP32S3)
  #define SERIAL_MONITOR_BAUD 460800
  //#define DISABLE_LOGGING // Xiao's setup with USB requires serial to be initialized on the IDE else it blocks
#else
  #define SERIAL_MONITOR_BAUD 115200
#endif

#define EEPROM_FACTORY_RESET 0           // Byte to be used for factory reset device fails to start or is rebooted within 1 sec 3 consequitive times
#define EEPROM_CONFIGURATION_START 1     // First EEPROM byte to be used for storing the configuration

#define FACTORY_RESET_CLEAR_TIMER_MS 2000   // Clear factory reset counter when elapsed, considered smooth boot

#if defined(CONFIG_IDF_TARGET_ESP32C3)
  #define INTERNAL_LED_PIN GPIO_NUM_8
  #define DEVICE_NAME "ESP32C3LED"
#elif defined(CONFIG_IDF_TARGET_ESP32S3)
  #define INTERNAL_LED_PIN LED_BUILTIN
  #define DEVICE_NAME "ESP32S3LED"
#elif defined(SEEED_XIAO_M0)
  #define INTERNAL_LED_PIN     13
#elif defined(CONFIG_IDF_TARGET_ESP32)
  #define INTERNAL_LED_PIN LED_BUILTIN
  #define DEVICE_NAME "ESP32LED"
#elif defined(ESP8266)
  #define INTERNAL_LED_PIN LED_BUILTIN
  #define DEVICE_NAME "ESP8266LED"
#else
  #define INTERNAL_LED_PIN LED_BUILTIN
  #define DEVICE_NAME "ESPXXLED"
#endif

#ifdef WIFI
    #define WIFI_SSID DEVICE_NAME
    #define WIFI_PASS "password123"

    // If unable to connect, it will create a soft accesspoint
    #define WIFI_FALLBACK_SSID DEVICE_NAME // device chip id will be suffixed
    #define WIFI_FALLBACK_PASS "password123"

    #define NTP_SERVER "pool.ntp.org"
    #define NTP_GMT_OFFSET_SEC 0  // GMT (default on factory reset)
    #define NTP_DAYLIGHT_OFFSET_SEC 0  // Deprecated, kept for compatibility

    // Web server
    #define WEB_SERVER_PORT 80

    // MQTT, disabled until a server is set on the Device page. Topics live under <MQTT_TOPIC>/<device id>.
    #define MQTT_PORT 1883
    #define MQTT_TOPIC "esp_led"
    #define MQTT_DISCOVERY_PREFIX "homeassistant"   // Home Assistant's default discovery prefix
    #define MQTT_RECONNECT_MS 60000     // Connecting blocks the loop while the broker is unreachable, so retry sparingly
    #define MQTT_TELEMETRY_MS 300000    // Every 5 min
    #define MQTT_SAVE_DELAY_MS 5000     // Commands from Home Assistant are saved once they stop changing
    #if defined(ESP8266)
      #define MQTT_BUFFER_SIZE 1024     // Largest incoming message (config JSON)
    #else
      #define MQTT_BUFFER_SIZE 2048
    #endif
#endif

#ifdef LED
    // LED layouts, selectable at /led. Values are persisted (configuration.ledLayout) - append only.
    #define LED_LAYOUT_SINGLE 0   // One strip on ledPin
    #define LED_LAYOUT_DUAL   1   // Two strips on ledPin + ledPin2, rendered end to end or mirrored
    #define LED_LAYOUT_RING   2   // One chain on ledPin: outer ring (ledRingOuterSize) followed by inner ring
    #define LED_LAYOUT_COUNT  3
    #define LED_LAYOUT_BIT(layout) (1 << (layout))
    #define LED_LAYOUTS_ALL   0xFF
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

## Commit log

2021-05-29 initial and broken
    [Configuration.h]
2021-05-30 lots of fixes in configuration and web requests
    [Configuration.h]
2021-05-31 code complete, web works
    [Configuration.h]
2022-03-02 Added OTA support with AsyncElegantOTA. Moved config over to Configuration.h
    [Configuration.h]
2022-03-07 wifi and ota working
    [Configuration.h]
2022-03-09 working wifi, logging fixes
    [Configuration.h]
2022-03-09 configurable led strip size
    [Configuration.h]
2022-03-09 Consolidating ESP32 and ESP8266. Added factory reset after 3 short reboots
    [Configuration.h]
2022-03-09 wifi name string fix
    [Configuration.h]
2022-03-18 updated readme, added stl for 3D printed enclosure
    [ESP32Case.stl, ESP32Lid.stl]
2022-03-19 description and images
    [Dark Ring.stl, Hanger.stl, Light Ring.stl]
2022-03-19 instructions in readme
    [DarkRing.stl, LightRing.stl]
2022-04-05 ring pallete mode
    [Configuration.h]
2022-06-13 small bug in lib dependencies and added Pride colors mode
    [main.cpp]
2022-12-06 minor fixes and lib updates
    [Configuration.cpp, WifiManager.cpp]
2023-12-24 WIP - power save mode web config
    [Configuration.h]
2023-12-25 WIP power save mode
    [Configuration.h]
2023-12-25 working powersave mode
2023-12-25 working powersave and support for both strip and ring
2025-10-18 refactor in progress to use PicoCSS and library update
    [Configuration.h]
2025-10-23 fix: fixed led form bugs
    [WifiManager.cpp]
2025-12-20 fix: led brightness init on startup without time
    [Configuration.h]
2025-12-21 LED type as a configurable option
    [Configuration.h]
2025-12-21 fix: added WS2811 as LED type
    [WifiManager.cpp, main.cpp]
2025-12-21 feat: displaying current mode and remaining time
2025-12-28 Xmas mode tweaks
    [Configuration.h]
2026-01-01 tweaks for the LED Cell build
    [Configuration.h]
2026-01-11 feat: PP mode and mode selection improvements
    [Configuration.h]
2026-01-16 feat: OLED support
    [Configuration.h]
2026-01-17 fix: small improvements to OLED support
    [Configuration.h]
2026-01-27 fix: esp8266 no oled and no button compile issues
    [Configuration.h]
2026-02-05 fix: OLED support improved
    [Configuration.h]
2026-02-06 feat: new charging mode
2026-02-07 feat: refactored LED logic in separate class
    [Configuration.h]
2026-02-08 fix: looping even if device has to reboot, and some minor post-AI refactors
    [LedManager.cpp, main.cpp]
2026-02-08 fix: shorter blocking on getLocalTime() and trimming web log buffer length
    [Configuration.h]
2026-02-08 fix: added device state and calling for time update only if connected to wifi
    [Configuration.h]
2026-02-08 feat: add timezone selection and update local time display in device settings
    [Configuration.h]
2026-02-21 feat: staranger things led mode and support
    [Configuration.h]
2026-05-05 faet: working number in solid mode on the latter 8x8 led matrix
2026-10-07 feat: added Claude and had it do some updates
    [Configuration.h]
2026-10-08 feat: configure LED layout, pins and color order from the web
    LED hardware was compiled in: RING_LIGHT, LED_PIN, LED_COLOR_ORDER and
    OUTTER_RING_SIZE meant a rebuild per build variant. It is now runtime
    configuration, set on a new /led page: layout (single strip, dual strip on
    two data pins - continuous or mirrored - or ring light with outer + inner
    ring), LED count(s), data pin(s), chipset and color order. The page saves
    and reboots; the form goes through the same validation as JSON imports, and
    rejected saves report the reason instead of reloading.
    FastLED takes pin and color order as template parameters, and instantiating
    every chipset x pin x order combination does not fit the ESP32 fla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
    [Configuration.h]
2026-10-08 feat: add a mode configurator and MQTT / Home Assistant support
    Mode Configurator (/modes): define up to 8 custom modes - name, 1-8 colors
    with smooth or hard transitions, effect, direction, speed and palette
    repeats. Effects depend on the layout: color fade, edge to edge and twinkle
    everywhere, center to edge on strips, circling, ring halves and ring to
    ring on a ring light; the page only offers the ones that fit the running
    layout. CCustomMode reads its slot from the configuration every frame, so
    saving takes effect without a reboot. All slots are registered after the
    built-in modes whether used or not, so built-in and custom mode indices
    stay fixed when slots are filled or emptied; new bu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
    [Configuration.h]
2026-10-08 feat: add an OTA partition migrator for 4MB ESP32 boards
    The esp32, esp32c3 and esp32s3 environments switched to min_spiffs.csv
    (two 1.9MB app slots) because the firmware outgrew the 1.25MB slots of the
    framework's default.csv. Devices still on default.csv can't take the new
    firmware over the air: OTA never rewrites the partition table, so /update
    rejects the 1.8MB image and the only way forward was USB.
    The *_migrator environments build src/migrator/ instead of the controller:
    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
2026-10-08 fix(led): pin ESP32 LED channels to the RMT driver
    On classic ESP32 the channel API's AUTO driver selection picks the I2S
    clockless engine (priority 10, above RMT's 2). It packs the whole frame
    into one contiguous DMA buffer of about 400 bytes per byte of LED data -
    ~150KB for the default 128 LEDs, ~320KB for the 267-LED RingLight - so
    the allocation fails, the engine logs "ChannelEngineI2sEsp32Dev: scratch
    buffer allocation failed" and drops the frame without falling back to
    another driver. The LEDs never update.
    Set ChannelOptions::mBus to RMT. It is FastLED's DefaultBus for clockless
    chipsets on ESP32, C3 and S3, i.e. what addLeds<>() used before the
    switch to runtime channels, and it st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
    [LedManager.cpp]
2026-10-08 fix(led): deepen RMT buffers to stop WiFi-induced flicker
    The RMT5 driver streams each frame through a ping-pong buffer refilled by
    an interrupt. With FastLED's default of 2 memory blocks (3 once it detects
    network activity) a refill is due roughly every 80us on a classic ESP32,
    and FastLED's own driver notes put WiFi interrupt latency at 50-120us. A
    late refill sends stale symbols, so the LEDs from that point to the end
    of the strip show garbage for a frame - an intermittent flicker towards
    the end of the strip that follows network traffic.
    Before adding the strips, give each one an equal share of the TX memory
    through RmtMemoryManager::setMemoryBlockStrategy(): 8 blocks for a single
    strip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
    [LedManager.cpp]
2026-10-08 feat(modes): share custom modes between controllers as a code
    Each saved mode on the Mode Configurator gets a Code button that shows it
    as one line of JSON (name, effect, colors, smooth, direction, speed,
    repeat) in a read-only input with a Copy button. Slot and index are left
    out since they are local to the device. A "Paste a mode code" field on the
    form loads such a code into the editor as a new, unsaved mode, so it can
    be reviewed or tweaked before Save.
    This is page-side only: POST /modes already takes exactly these fields and
    validates them in firmware. The page still checks a code before loading
    it, with specific messages for invalid JSON, a missing name, an effect
    this firmware doesn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
2026-10-09 feat(modes): add seven custom-mode effects, flame center and ring options
    New Mode Configurator effects, all layouts: falling stars (heads in the
    first color racing toward an end, trails fading through the others),
    flickering flame (Fire2012, heat mapped onto the colors from black),
    breathing, theater chase, scanner, color wipe and lightning. They are
    appended after the existing effect values, so saved modes keep their
    meaning.
    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
    [Configuration.h]
2026-10-10 feat(modes): select several modes to cycle through on the main page
    The main page's single "LED Mode" dropdown and the separate cycling panel
    (a "cycle all" box and a comma-separated list of mode indices) are
    replaced by one checkbox per mode available on the running layout. One
    checked mode stays; several are cycled through every "Change mode every
    (seconds)". The browser blocks submitting with none checked. The selection
    is the existing cycleModesList/cycleModesCount, so /api, MQTT and backups
    are unchanged, and the older count-0 "every mode" setting still cycles
    everything and shows all boxes checked.
    The showing mode is always checked, so saving an unrelated setting never
    switches away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
2026-10-22 feat(modes): two-modes ring effect and clock-synchronized mode changes
    Two modes (custom effect, ring layout only): a mode that plays one regular
    mode on the outer ring and another on the inner. Each source draws a
    full-length frame into its own buffer, which is scaled onto its ring so
    the whole pattern shows rather than a cut of it; keeping the buffer
    between frames lets twinkle or the scanner's tail work as usual, and the
    same mode on both rings is drawn once. Sources must work on a single
    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
2026-10-25 fix(wifi): keep the web server reachable after WiFi drops
    Devices kept running modes and posting to MQTT but stopped answering
    HTTP requests.
    - Disable modem sleep on ESP32 (ESP8266 already did). While dozing the
    radio misses ARP requests and incoming connections, so peers whose ARP
    entry expired time out, while the device's own MQTT connection works.
    - Register routes and start the server once. Ending it on a disconnect
    and restarting it on reconnect failed to bind port 80 while earlier
    connections were open or in TIME_WAIT, leaving no listener, and each
    reconnect registered every handler again.
2026-10-26 build(deps): switch to ElegantOTA Pro
    Replace ayushsharma82/ElegantOTA with the commercial ElegantOTA Pro from
    its private repository (softt-io/ElegantOTA-Pro). Pro keeps the global
    ElegantOTA object, begin()/loop() and the ELEGANTOTA_USE_ASYNC_WEBSERVER
    switch, but its header is ElegantOTAPro.h, which is the only code change.
    loop() is still called before begin() (WiFi not up yet); in Pro that only
    checks idle remote-update state, so it is safe.
    Pro compiles in remote download / update channels by default
    (ELEGANTOTA_ENABLE_REMOTE=1), which adds an HTTP/HTTPS client: flash is
    now esp32 84.9%, esp32c3 85.5%, esp32s3 95.7%, seeed_xiao_esp32s3 56.0%,
    esp8266 77.0% (RAM 60.4%). Setting ELEGANT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
2026-10-28 feat(board): XIAO ESP32S3 defaults and pin list
    The seeed_xiao_esp32s3 environment compiled with the generic ESP32-S3
    settings, which don't match the board:
    - /led offered every S3 GPIO, most of which the XIAO doesn't bring out.
    It now lists only the header pads, D0-D10 (GPIO 1-9, 43, 44).
    - The default LED data pin is GPIO 3 (pad D2); the second strip stays on
    GPIO 4 (D3).
    - The user LED on GPIO 21 is active-low, so the status LED was inverted.
    - The WiFi power default is the maximum, 19.5dBm, instead of the
    8.5dBm used for the C3/S3 dev boards. Like the other defaults, it
    applies only after a factory reset or to a device with no saved settings.
    The environment also gets the same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
